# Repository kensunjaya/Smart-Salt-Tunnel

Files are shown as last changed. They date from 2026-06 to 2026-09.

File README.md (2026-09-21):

# Smart-Salt-Tunnel
Smart Salt Tunnel Schema, Integration Code + NRF24L01 communication

Schematic_Smart-Salt-Tunnel-std-v1_2026-09-18-2-1

```text
TDS Sensor      Arduino
-----------------------
VCC         -> 5V
GND         -> GND
AO          -> A1
```

```text
Salinity Sensor    Arduino
---------------------------
VCC            -> 5V
GND            -> GND
OUT            -> A0
```

```text
Water Level Sensor    Arduino
--------------------------------
+                 -> 5V
-                 -> GND
S                 -> A2
```

```text
DS18B20         Arduino
------------------------
VCC         -> 5V
GND         -> GND
DATA        -> D2
```

```text
HTU21D      Arduino
--------------------
+       -> 3.3V
-       -> GND
DA      -> A4
CL      -> A5
```

```text
NRF24L01      Arduino
----------------------
VCC       -> 3.3V
GND       -> GND
CE        -> D7
CSN       -> D8
MOSI      -> D11
MISO      -> D12
SCK       -> D13
IRQ       -> NC
```

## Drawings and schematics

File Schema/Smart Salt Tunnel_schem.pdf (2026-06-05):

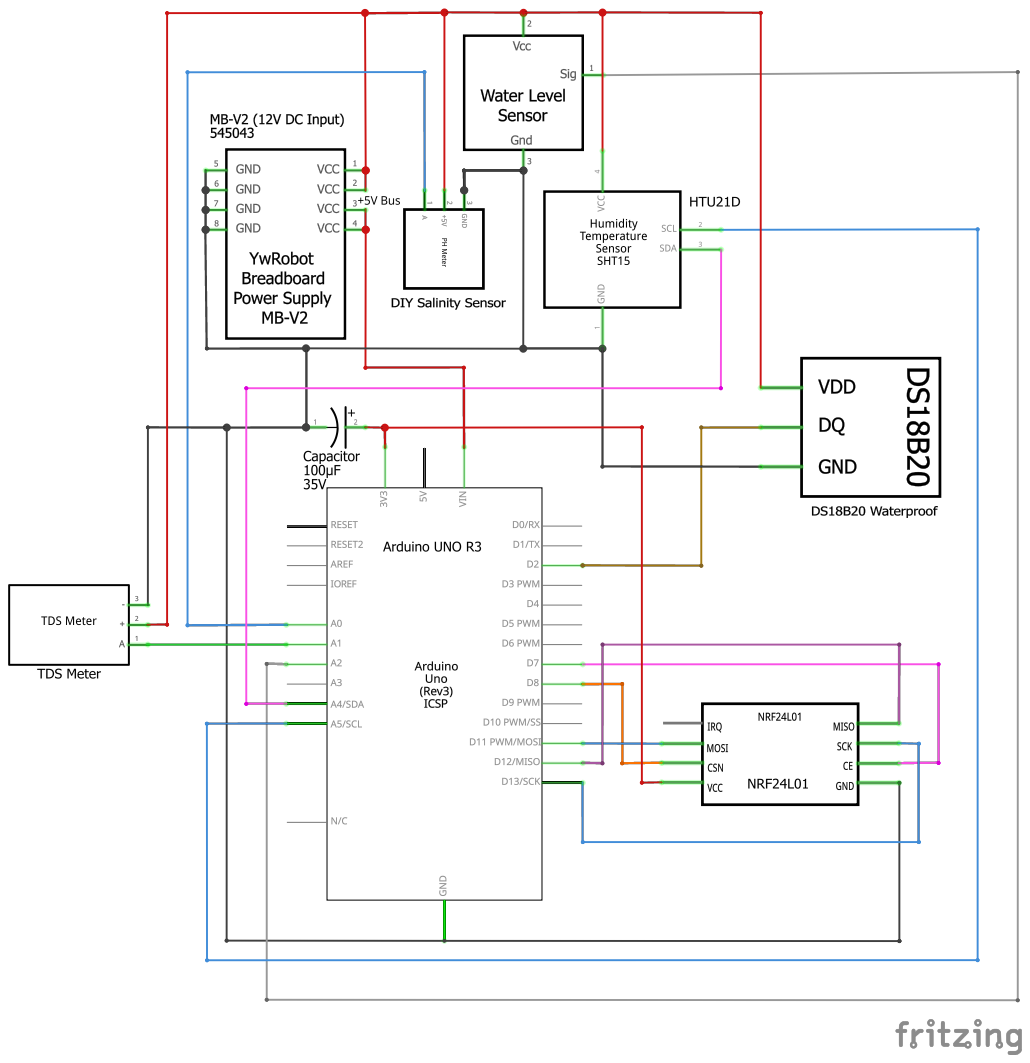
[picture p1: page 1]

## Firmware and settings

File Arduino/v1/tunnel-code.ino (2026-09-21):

/*
SMART SALT TUNNEL v1
Author: Kenneth Sunjaya
Last Updated: 22 September 2026
*/

#include <EEPROM.h>
#include <Wire.h>
#include <SPI.h>
#include <RF24.h>
#include <Adafruit_HTU21DF.h>
#include <OneWire.h>
#include <DallasTemperature.h>

// RADIO CONFIGURATION
#define CE_PIN 9
#define CSN_PIN 10
#define RELAY_PIN 5
#define WATER_LEVEL_PIN A2
#define WATER_TEMP_PIN A3
#define DMS_S_PIN 6
#define DMS_ANALOG_PIN A0

Adafruit_HTU21DF htu = Adafruit_HTU21DF();
OneWire oneWire(WATER_TEMP_PIN);
DallasTemperature waterTempSensor(&oneWire);
RF24 radio(CE_PIN, CSN_PIN);

const byte RASPI_ADDRESS[6] = "RASPI"; // harus sama juga di sisi RPi
byte DEVICE_ADDRESS[6]; // unique identifier untuk setiap tunnel

const uint8_t PAYLOAD_SIZE = 32;

// MESSAGE TYPES MAPPING
const uint8_t MSG_REGISTER_REQUEST = 1;
const uint8_t MSG_REGISTER_ACK = 2;
const uint8_t MSG_TELEMETRY = 3;
const uint8_t MSG_START_TRANSFER = 4;
const uint8_t MSG_TRANSFER_COMPLETE = 5;
const uint8_t MSG_SET_STATUS = 6;


// REGISTRATION STATUS
const uint8_t STATUS_UNREGISTERED = 0;
const uint8_t STATUS_DISABLED = 1;
const uint8_t STATUS_ENABLED = 2;


// DEVICE STATE
enum DeviceState {
  REGISTERING,
  UNREGISTERED,
  DISABLED,
  ENABLED
};

DeviceState device_state = REGISTERING;


// TIMING CONFIG
const unsigned long REGISTER_RETRY_INTERVAL = 20000; // interval retry kirim register request jika gagal.
const unsigned long TELEMETRY_INTERVAL = 10000; // interval tunnel kirim telemetry
const unsigned long TELEMETRY_JITTER = 1000; // range untuk jitter interval yang diperbolehkan, untuk menghindari beberapa tunnel kirim telemetry secara bersamaan

unsigned long current_telemetry_interval = TELEMETRY_INTERVAL;
unsigned long last_register_attempt = 0;
unsigned long last_telemetry_timestamp = 0;


// MESSAGE STATE
uint32_t telemetry_sequence = 0;
uint32_t active_message_id = 0;
uint32_t last_completed_message_id = 0;
uint16_t active_min_level = 0;
bool transfer_active = false;
unsigned long last_transfer_check = 0;
const unsigned long TRANSFER_CHECK_INTERVAL = 500;

bool is_htu_available = true;
bool is_water_temp_available = true;

// baca tunnel id dari EEPROM
bool loadDeviceAddress() {
  for (uint8_t i = 0; i < 5; i++) {
    DEVICE_ADDRESS[i] = EEPROM.read(i);

    if (DEVICE_ADDRESS[i] == 0xFF) {
      return false;
    }
  }

  DEVICE_ADDRESS[5] = '\0';

  return true;
}

// HELPER FUNCTIONS

void writeUInt16LE(byte* buffer, int offset, uint16_t value) {
  buffer[offset] = value & 0xFF;
  buffer[offset + 1] = (value >> 8) & 0xFF;
}

void writeInt16LE(byte* buffer, int offset, int16_t value) {
  writeUInt16LE(buffer, offset, (uint16_t)value);
}

void writeUInt32LE(byte* buffer, int offset, uint32_t value) {
  buffer[offset] = value & 0xFF;
  buffer[offset + 1] = (value >> 8) & 0xFF;
  buffer[offset + 2] = (value >> 16) & 0xFF;
  buffer[offset + 3] = (value >> 24) & 0xFF;
}

uint16_t readUInt16LE(byte* buffer, int offset) {
  return (
    ((uint16_t)buffer[offset]) |
    ((uint16_t)buffer[offset + 1] << 8)
  );
}

uint32_t readUInt32LE(byte* buffer, int offset) {
  return (
    ((uint32_t)buffer[offset]) |
    ((uint32_t)buffer[offset + 1] << 8) |
    ((uint32_t)buffer[offset + 2] << 16) |
    ((uint32_t)buffer[offset + 3] << 24)
  );
}


// RADIO INITIALIZATION

void initializeRadio() {
  if (!radio.begin()) {
    Serial.println(F("ERROR: nRF24 not detected"));
    while (true);
  }

  radio.setChannel(76);
  radio.setDataRate(RF24_250KBPS);
  radio.setPALevel(RF24_PA_LOW);
  radio.setPayloadSize(PAYLOAD_SIZE);
  radio.setAutoAck(true); // enhanced shockburst autoack (ESB)
  radio.setRetries(5, 15); // retry delay, banyaknya retry yg diperbolehkan

  radio.openReadingPipe(1, DEVICE_ADDRESS);
  radio.openWritingPipe(RASPI_ADDRESS);

  radio.flush_rx();
  radio.startListening();
}


// REGISTER REQUEST

void sendRegisterRequest() {
  byte packet[PAYLOAD_SIZE] = {0};

  packet[0] = MSG_REGISTER_REQUEST;
  memcpy(&packet[1], DEVICE_ADDRESS, 5);

  radio.stopListening();

  bool success = radio.write(packet, PAYLOAD_SIZE);

  radio.startListening();

  Serial.print(F("(TX) REGISTER_REQUEST -> RPi"));

  if (success) {
    Serial.println(F(" [ACK]"));
  } else {
    Serial.println(F(" [FAILED]"));
  }
}


// REGISTER ACK

void handleRegisterAck(byte* packet) {
  uint8_t status = packet[6];

  Serial.print(F("(RX) REGISTER_ACK <- Pi"));

  if (status == STATUS_ENABLED) {
    device_state = ENABLED;
    last_telemetry_timestamp = millis();
  
    generateNextTelemetryInterval();
  
    Serial.println(F("STATUS: ENABLED"));
  }

  else if (status == STATUS_DISABLED) {
    device_state = DISABLED;
    Serial.println(F("STATUS: DISABLED"));
  }

  else {
    device_state = UNREGISTERED;
    Serial.println(F("STATUS: UNREGISTERED"));
  }
}

void handleSetStatus(byte* packet) {
  uint8_t status = packet[6];

  if (status == STATUS_DISABLED) {
    device_state = DISABLED;

    digitalWrite(RELAY_PIN, HIGH); // jika status disabled dikirimkan, maka langsung paksa matikan pompa

    if (transfer_active) {
      transfer_active = false;
      active_message_id = 0;

      Serial.println(F("Active transfer cancelled"));
    }

    Serial.println(F("(RX) DEVICE DISABLED"));
    Serial.println(F("(-) PUMP: OFF"));
    return;
  }

  if (status == STATUS_ENABLED) {
    device_state = ENABLED;
  
    last_telemetry_timestamp = millis(); // reset last telemetry timetamp agar menghindari telemetry langsung terkirim jika memang sudah jatuh tempo
    generateNextTelemetryInterval();
  
    Serial.println(F("(RX) DEVICE ENABLED"));
  }
}


// START TRANSFER

void handleStartTransfer(byte* packet) {
  if (device_state != ENABLED) {
    return;
  }

  uint32_t message_id = readUInt32LE(packet, 6);
  uint16_t min_level = readUInt16LE(packet, 10);

  Serial.println();
  Serial.println(F("(RX) START_TRASNFER"));

  Serial.print(F("message_id="));
  Serial.println(message_id);

  Serial.print(F("min_level="));
  Serial.println(min_level);

  // jika masih ada transfer yang sedang berjalan
  if (transfer_active) {
    if (message_id == active_message_id) {
      Serial.println(F("Transfer already active"));
    } else {
      Serial.println(F("Another transfer is already active, ignoring"));
    }

    return;
  }

  // transfer ini udah selesai sebelumnya
  if (message_id == last_completed_message_id) {
    Serial.println(F("Transfer already completed, resending TRANSFER_COMPLETE"));
    sendTransferComplete(last_completed_message_id);
    return;
  }

  // mulai transfer air
  active_message_id = message_id;
  active_min_level = min_level;
  transfer_active = true;

  last_transfer_check = 0;

  digitalWrite(RELAY_PIN, LOW);

  Serial.println(F("(+) PUMP: ON"));
}

void handleTransfer() {
  // Serial.println(F("Handling Transfer..."));
  if (!transfer_active) {
    return;
  }

  unsigned long now = millis();

  if (last_transfer_check != 0 &&
      now - last_transfer_check < TRANSFER_CHECK_INTERVAL) {
    return;
  }

  last_transfer_check = now;

  uint16_t water_level = getWaterLevel();

  Serial.print(F("Transfer water_level="));
  Serial.print(water_level);

  Serial.print(F(" min_level="));
  Serial.println(active_min_level);

  if (water_level <= active_min_level) {
    digitalWrite(RELAY_PIN, HIGH);
  
    Serial.println(F("(-) PUMP: OFF"));
    Serial.println(F("*** MINIMUM WATER LEVEL REACHED ***"));
  
    uint32_t completed_message_id = active_message_id;
  
    transfer_active = false;
    active_message_id = 0;
  
    last_completed_message_id = completed_message_id;
  
    // jangan langsung kirim telemetry setelah transfer selesai
    last_telemetry_timestamp = millis();
    generateNextTelemetryInterval();
  
    sendTransferComplete(completed_message_id);
  
    Serial.print(F("TRANSFER IS COMPLETED: "));
    Serial.println(transfer_active);
  }
}

// TRANSFER COMPLETE
void sendTransferComplete(uint32_t message_id) {
  byte packet[PAYLOAD_SIZE] = {0};

  packet[0] = MSG_TRANSFER_COMPLETE;
  memcpy(&packet[1], DEVICE_ADDRESS, 5);
  writeUInt32LE(packet, 6, message_id);

  Serial.println(F("++ Sending Transfer Complete via Radio..."));

  radio.stopListening();

  bool success = radio.write(packet, PAYLOAD_SIZE);

  radio.startListening();

  Serial.print(F("TRANSFER_COMPLETE -> RPi, message_id="));
  Serial.print(message_id);

  if (success) {
    Serial.println(F(" [ACK]"));
  } else {
    Serial.println(F(" [FAILED]"));
  }
}

// CEK BUFFER FIFO RX
void checkIncomingRadio() {
  // Serial.println(F("Checking for incoming radio..."));
  if (!radio.available()) {
    return;
  }

  byte packet[PAYLOAD_SIZE] = {0};

  radio.read(packet, PAYLOAD_SIZE);

  // DEBUG RAW PACKET
  Serial.print(F("RX RAW: "));

  for (uint8_t i = 0; i < 12; i++) {
    if (packet[i] < 0x10) {
      Serial.print('0');
    }

    Serial.print(packet[i], HEX);
    Serial.print(' ');
  }

  Serial.println();


  // CEK APAKAH PACKET ISINYA SEMUA 0x00
  bool all_zero = true;

  for (uint8_t i = 0; i < PAYLOAD_SIZE; i++) {
    if (packet[i] != 0) {
      all_zero = false;
      break;
    }
  }
  // jika packet isinya 0 semua, buang paket
  if (all_zero) {
    Serial.println(F("WARNING: ZERO PACKET DETECTED"));
    radio.flush_rx();
    return;
  }


  uint8_t message_type = packet[0];

  if (message_type == MSG_REGISTER_ACK) {
    handleRegisterAck(packet);
  }

  else if (message_type == MSG_START_TRANSFER) {
    handleStartTransfer(packet);
  }

  else if (message_type == MSG_SET_STATUS) {
    handleSetStatus(packet);
  }

  else {
    Serial.print(F("WARNING: UNKNOWN MESSAGE TYPE: "));
    Serial.println(message_type);
  }
}
// REGISTRATION
void handleRegistration() {
  // Serial.println(F("Handling Registration..."));
  if (device_state != REGISTERING && device_state != UNREGISTERED) {
    return;
  }

  unsigned long now = millis();

  if (last_register_attempt == 0 || now - last_register_attempt >= REGISTER_RETRY_INTERVAL) {
    last_register_attempt = now;
    sendRegisterRequest();
  }
}

// SENSOR READINGS
int16_t getWaterTemp() {
  if (!is_water_temp_available) {
    return -1;
  }
  waterTempSensor.requestTemperatures();
  float temperature = waterTempSensor.getTempCByIndex(0);
  return (int16_t)(temperature * 100);
}

int16_t getAirTemp() {
  if (!is_htu_available) {
    return -1;
  }

  float temperature = htu.readTemperature();

  if (isnan(temperature)) {
    Serial.println(F("WARNING: HTU21D temperature read failed"));
    return -1;
  }

  return (int16_t)(temperature * 100);
}

int16_t getHumidity() {
  if (!is_htu_available) {
    return -1;
  }

  float humidity = htu.readHumidity();

  if (isnan(humidity)) {
    Serial.println(F("WARNING: HTU21D humidity read failed"));
    return -1;
  }

  return (int16_t)(humidity * 100);
}

int16_t getPH() {
  // TODO
  return -1;
}

uint16_t getSalinityADC(uint8_t pin, uint8_t sample_count) {
  uint32_t total = 0;
  uint16_t min_value = 1023;
  uint16_t max_value = 0;
  // trimmed mean ADC
  for (uint8_t i = 0; i < sample_count; i++) {
    uint16_t value = analogRead(pin);
    total += value;

    if (value < min_value) {
      min_value = value;
    }
    if (value > max_value) {
      max_value = value;
    }

    delay(2);
  }

  total -= min_value;
  total -= max_value;

  return total / (sample_count - 2);
}

uint16_t getSalinity() {
  digitalWrite(DMS_S_PIN, LOW); // DMS ON (active LOW)

  delay(100); // tunggu sebentar sampai sensor stabil

  // buang ADC reading pertama
  analogRead(DMS_ANALOG_PIN);

  uint16_t adc_value = getSalinityADC(DMS_ANALOG_PIN, 20);

  digitalWrite(DMS_S_PIN, HIGH); // DMS OFF

  // ADC -> konduktivitas (uS/cm)
  // ini masih pakai kalibrasi bawaan dari penjual
  float conductivity = (0.2142f * adc_value) + 494.93f;

  // konduktivitas -> salinitas (ppt)
  float salinity = conductivity * 0.00064f;

  Serial.print(F("Salinity ADC="));
  Serial.print(adc_value);

  Serial.print(F(" conductivity="));
  Serial.print(conductivity, 2);

  Serial.print(F(" uS/cm salinity="));
  Serial.print(salinity, 2);
  Serial.println(F(" ppt"));

  return (uint16_t)(salinity * 100.0f + 0.5f);
}

uint16_t getWaterLevel() {
  // trimmed mean
  const uint8_t sample_count = 10;

  uint32_t total = 0;
  uint16_t min_value = 1023;
  uint16_t max_value = 0;

  for (uint8_t i = 0; i < sample_count; i++) {
    uint16_t value = analogRead(WATER_LEVEL_PIN);

    total += value;
    
    if (value < min_value) {
      min_value = value;
    }
    if (value > max_value) {
      max_value = value;
    }

    delay(2);
  }
  
  // buang outlier nilai tertinggi dan terendah
  total -= min_value;
  total -= max_value;

  return total / (sample_count - 2);
}


// SEND TELEMETRY

void sendTelemetry() {
  byte packet[PAYLOAD_SIZE] = {0};
  Serial.println(F("Reading water temperature..."));
  int16_t water_temp = getWaterTemp();
  Serial.println(F("Reading air temperature..."));
  int16_t air_temp = getAirTemp();
  Serial.println(F("Reading humidity..."));
  int16_t humidity = getHumidity();
  Serial.println(F("Reading pH..."));
  int16_t ph = getPH();
  Serial.println(F("Reading salinity..."));
  uint16_t salinity = getSalinity();
  Serial.println(F("Reading water level..."));
  uint16_t water_level = getWaterLevel();

  packet[0] = MSG_TELEMETRY;

  memcpy(&packet[1], DEVICE_ADDRESS, 5);

  writeUInt32LE(packet, 6, telemetry_sequence);
  writeInt16LE(packet, 10, water_temp);
  writeInt16LE(packet, 12, air_temp);
  writeInt16LE(packet, 14, humidity);
  writeUInt16LE(packet, 16, water_level);
  writeUInt16LE(packet, 18, salinity);
  writeInt16LE(packet, 20, ph);
  Serial.println(F("Ready to send telemetry to RPi..."));

  radio.stopListening();
  bool success = radio.write(packet, PAYLOAD_SIZE);
  radio.startListening();
  
  Serial.print(F("TEL "));
  Serial.print(telemetry_sequence);

  Serial.print(F(" water_level="));
  Serial.print(water_level);

  Serial.print(F(" salinity="));
  Serial.print(salinity / 100.0);

  Serial.print(F(" water_temp="));
  Serial.print(water_temp / 100.0);

  Serial.print(F(" air_temp/humid="));
  Serial.print(air_temp / 100.0);
  Serial.print(F("/"));
  Serial.print(humidity / 100.0);
  Serial.print(F("%"));

  if (success) {
    Serial.println(F(" [ACK]"));
  } else {
    Serial.println(F(" [FAILED]"));
  }
  telemetry_sequence++;
}

// menambahkan offset jitter pada telemetry interval secara acak
void generateNextTelemetryInterval() {
  long jitter = random(-(long)TELEMETRY_JITTER, (long)TELEMETRY_JITTER + 1);
  current_telemetry_interval = TELEMETRY_INTERVAL + jitter;
}

// TELEMETRY (menentukan akan kirim telemetry atau tidak)
void handleTelemetry() {
  // Serial.println(F("Handling Telemetry..."));
  if (device_state != ENABLED || transfer_active) {
    return;
  }

  unsigned long now = millis();

  if (now - last_telemetry_timestamp >= current_telemetry_interval) {
    last_telemetry_timestamp = now;
    sendTelemetry();
    generateNextTelemetryInterval();
  }
}

void setup() {
  Serial.begin(115200);

  if (!loadDeviceAddress()) {
    Serial.println(F("ERROR: Device ID not configured"));
    while (true);
  }

  Serial.print(F("[LOADED] Device ID: "));
  Serial.println((char*)DEVICE_ADDRESS);

  randomSeed(analogRead(A1)); // random seed noise untuk jitter interval

  pinMode(RELAY_PIN, OUTPUT);
  digitalWrite(RELAY_PIN, HIGH); // Relay OFF

  pinMode(DMS_S_PIN, OUTPUT);
  digitalWrite(DMS_S_PIN, HIGH); // DMS OFF

  delay(2000);

  Wire.begin();
  Wire.setWireTimeout(10000, true);

  is_htu_available = htu.begin();

  if (!is_htu_available) {
    Serial.println(F("Air Temp & Humidity Sensor not detected"));
  }

  waterTempSensor.begin();
  // waktu pembacaan waterTempSensor adalah ~750ms karena 12bit. bisa dikurangi menjadi ~188ms jika diset ke 10bit tapi presisinya berkurang
  // waterTempSensor.setResolution(10);
  is_water_temp_available = waterTempSensor.getDeviceCount() > 0;

  if (!is_water_temp_available) {
    Serial.println(F("Water Temperature Sensor not detected"));
  }

  initializeRadio();

  Serial.println();
}

void loop() {
  checkIncomingRadio();
  handleRegistration();
  handleTelemetry();
  handleTransfer();
}

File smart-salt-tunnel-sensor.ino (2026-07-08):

// Library yang harus diinstal: RF24, OneWire, DallasTemperature, DHT sensor library
#include <SPI.h>
#include <RF24.h>
#include <OneWire.h>
#include <DallasTemperature.h>
#include <DHT.h>

// DS18B20
#define ONE_WIRE_BUS A3

// DHT11
#define DHT_PIN 7
#define DHT_TYPE DHT11

// NRF24L01
#define NRF_CE_PIN 9
#define NRF_CSN_PIN 10

// Analog sensors
#define WATER_LEVEL_PIN A2
#define DMS_ANALOG_PIN A1
#define DMS_S_PIN 4

OneWire oneWire(ONE_WIRE_BUS);
DallasTemperature waterTemperature(&oneWire);

DHT dht(DHT_PIN, DHT_TYPE);

RF24 radio(NRF_CE_PIN, NRF_CSN_PIN);
const byte radioAddress[6] = "TUNL1";

// nrf24 payload
struct SensorData {
  float waterTemperature;
  float airTemperature;
  float humidity;
  int waterLevel;
  float salinitas;
};

SensorData data;

int readAverageADC(int pin, int samples) {
  long total = 0;
  for (int i = 0; i < samples; i++) {
    total += analogRead(pin);
    delay(10);
  }
  return total / samples;
}

float readSalinitas() {
  digitalWrite(DMS_S_PIN, LOW); // Mengaktifkan DMS

  Serial.println(F("DMS ACTIVE. Waiting 10 seconds until DMS stabilizes"));
  
  delay(10000);

  // Read ADC
  int adcVal = readAverageADC(DMS_ANALOG_PIN, 20);

  Serial.print(F("ADC sensor salinitas: "));
  Serial.println(adcVal);

  // ADC -> konduktivitas (uS/cm)
  float konduktivitas = (0.2142 * adcVal) + 494.93;

  Serial.print(F("Konduktivitas: "));
  Serial.print(konduktivitas);
  Serial.println(F(" uS/cm"));

  // konduktivitas -> salinitas (ppt)
  float salinitas = konduktivitas * 0.00064;

  digitalWrite(DMS_S_PIN, HIGH); // Disable DMS

  Serial.println(F("DMS OFF"));
  Serial.println();

  return salinitas;
}


void setup() {

  Serial.begin(9600);
  
  // DS18B20
  waterTemperature.begin();

  // DHT11
  dht.begin();

  // setup pin
  pinMode(WATER_LEVEL_PIN, INPUT);
  pinMode(DMS_ANALOG_PIN, INPUT);
  pinMode(DMS_S_PIN, OUTPUT);

  digitalWrite(DMS_S_PIN, HIGH); // non-aktifkan DMS

  // NRF24 setup
  if (!radio.begin()) {
    Serial.println(F("NRF24 NOT DETECTED"));
    while (1) {
      delay(1000);
    }
  }

  radio.openWritingPipe(radioAddress);
  radio.setPALevel(RF24_PA_LOW);
  radio.setDataRate(RF24_1MBPS);
  radio.stopListening();

  Serial.println(F("Done setup"));
  Serial.println();
}


void loop() {
  getSensorData();
  printSensorData();
  sendSensorData();
  delay(2000);
}

void getSensorData() {
  // baca DS18B20
  waterTemperature.requestTemperatures();
  data.waterTemperature = waterTemperature.getTempCByIndex(0);

  // baca DHT11
  data.airTemperature = dht.readTemperature();
  data.humidity = dht.readHumidity();

  // baca water level sensor
  data.waterLevel = analogRead(WATER_LEVEL_PIN);

  // baca sensor salinitas
  data.salinitas = readSalinitas();
}

void printSensorData() {
  Serial.println(F("----- NRF PAYLOAD -----"));
  Serial.print(F("Water Temperature : "));
  Serial.print(data.waterTemperature);
  Serial.println(F(" C"));

  Serial.print(F("Air Temperature   : "));
  Serial.print(data.airTemperature);
  Serial.println(F(" C"));

  Serial.print(F("Humidity          : "));
  Serial.print(data.humidity);
  Serial.println(F(" %"));

  Serial.print(F("Water Level ADC   : "));
  Serial.println(data.waterLevel);

  Serial.print(F("Salinitas         : "));
  Serial.print(data.salinitas);
  Serial.println(F(" ppt"));
  
  Serial.println();
}

void sendSensorData() {
  bool success = radio.write(&data, sizeof(data));

  if (success) {
    Serial.println(F("NRF24: Data transmitted successfully"));
  } 
  else {
    Serial.println(F("NRF24: Transmission failed"));
  }
}

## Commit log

2026-06-05 modify breadboard design
    [Smart Salt Tunnel.fzz]
2026-06-18 update schematic
2026-07-08 add new smart-salt-tunnel-sensor code
2026-09-12 added jitter to interval
    [tunnel-code.ino]
2026-09-12 add EEPROM support and sensor availability checks
2026-09-21 bug fix: arduino freezes after transfer has finished
    Added I2C wire timeout so arduino won't wait forever while trying to read HTU21D air temperature & humidity
    [tunnel-code.ino]
2026-09-21 Revise schematic in README
2026-09-25 add raspberry pi code
2026-10-17 add kode konversi adc -> salinitas (ppt)
2026-10-26 adc -> ppt code with temperature compensation
2026-10-27 - added ph and salinity conversions code in python - implemented ph reading in arduino code
2026-10-29 fix: handle edge cases in ADC to ppt and ppt to SG conversions
2026-10-31 Update schematic image in README.md
2026-10-31 implement average filtering on getPH function
